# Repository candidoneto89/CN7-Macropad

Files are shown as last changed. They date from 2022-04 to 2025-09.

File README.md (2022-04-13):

# CN7 Macropad

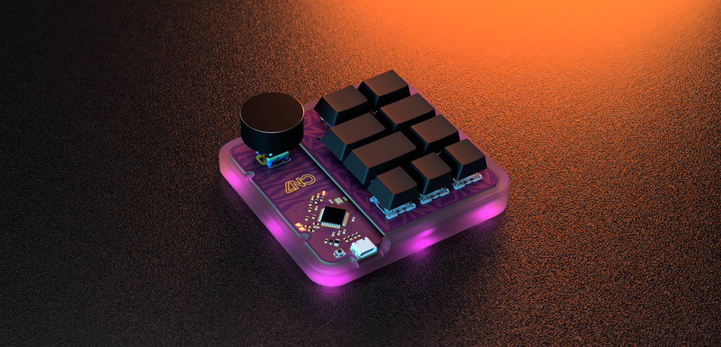
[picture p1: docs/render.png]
CN7 Macropad


**CN7 Macropad** is a custom-built mechanical keyboard, packing features:
- 9 programmable keys made for shortcuts;
- layer-indication LEDs;
- rotary encoder for commands such as media control and CAD features like zoom, etc;
- RGB addressable LEDs for underglow and individual key-lightning;

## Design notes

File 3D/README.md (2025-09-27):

## Building partlist:

Stacked Acrylic:
- 8x M2x6mm screws
- 4x M2x2mm screws
- 4x M2x12mm round standoffs
- 2x M2x6mm round standoffs

Open case:
- 3x M2 threaded inserts
- 3x M2x10mm screw

Closed case:
- 4x M2 threaded inserts
- 4x M2x10mm screw
- 1x 27x44x3mm acrylic sheet
- 1x 84x78x3mm acrylic sheet

## Stacked Acrylic 
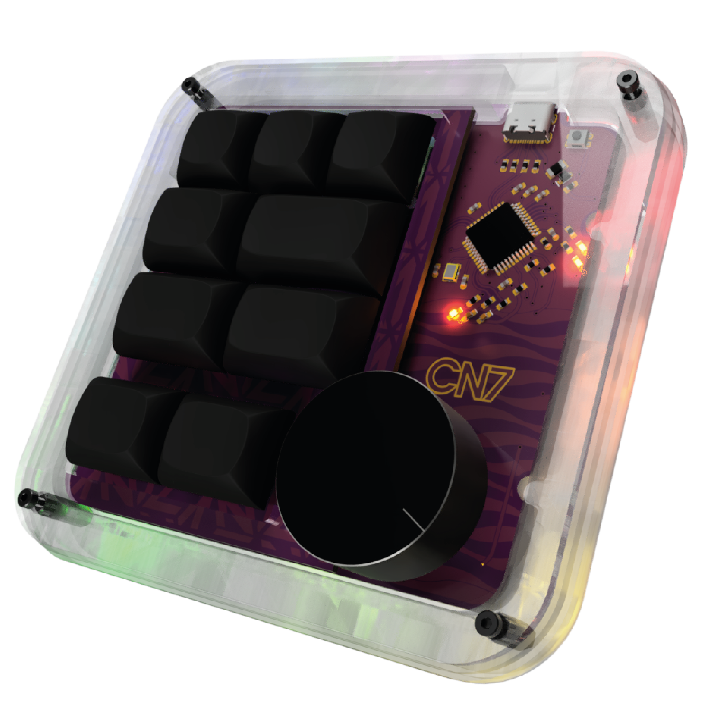
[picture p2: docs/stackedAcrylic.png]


## Open Case 
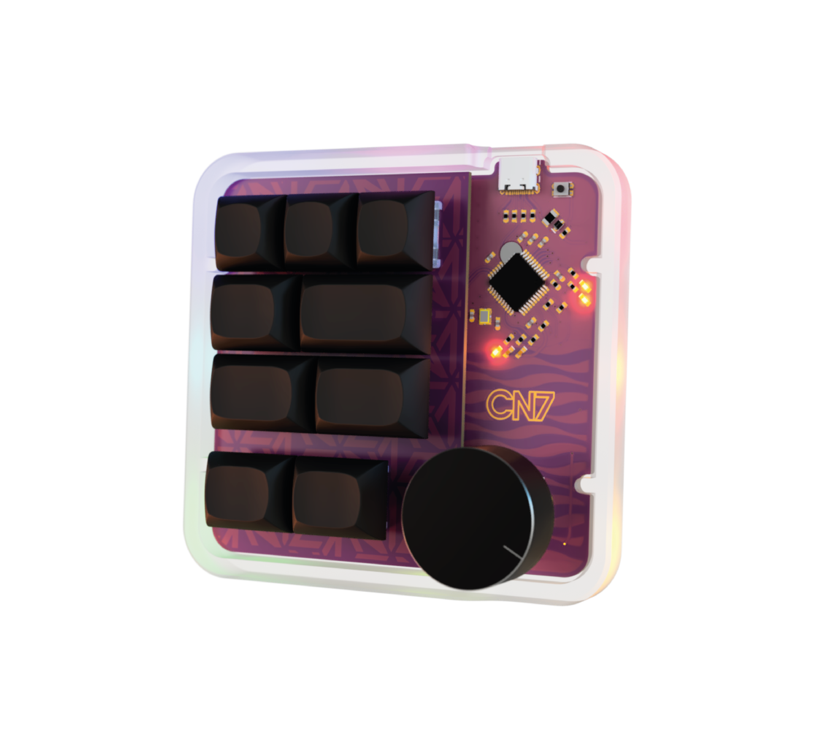
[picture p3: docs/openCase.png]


## Closed Case 
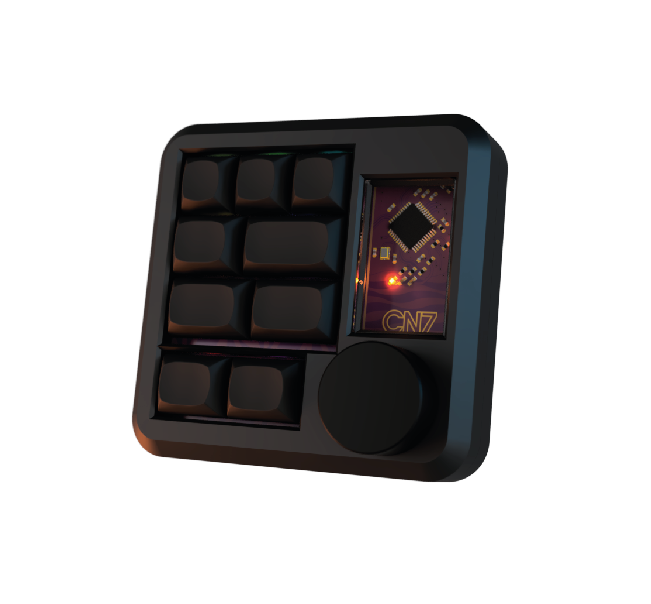
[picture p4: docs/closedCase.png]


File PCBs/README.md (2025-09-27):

# BOM
|Parts |Value |Package |Qty |
|---|---|---|---|
|C1 |10uF |0603-CAP |1 |
|C2, C3, C4, C5, C6 |1.0uF |0603-CAP |5 |
|C7, C8 |22pF |0603-CAP |2 |
|C9, C10, C11, C12, C13, C14, C15, C16, <br>C17, C18, C19, C20, C21, C22, C23, C24, C25|0.1uf|0603|17 |
|D1 |3A/10V/280mV |SOD-323 |1 |
|D12, D13 | |SOD-523 |2 |
|D2, D3, D4, D14, D15 | |LED-0603 |5 |
|D5, D6, D7, D8, D9, D10, D11 | |SOD-523 |7 |
|J2 |USB-C Connector |GCT_USB4105_REVA |1 |
|LED_1, LED_2, LED_3, LED_4, LED_5, LED_6, LED_7, LED_8, LED_9|SK6812-MINI-E|SK6812-MINI-E |9 |
|LED_10 |WS2812B5050 |WS2812B |1 |
|LED_11, LED_12, LED_13, LED_14, LED_15, LED_16, LED_17 |WS2812B5050 |WS2812B |7 |
|R1, R2 |5.1k |R0603 |2 |
|R10, R11, R12, R14, R15 |200 |R0603 |5 |
|R3, R4 |22 |R0603 |2 |
|R5, R6, R7, R8, R13 |10k |R0603 |5 |
|R9 |500 |R0603 |1 |
|S2 |KMR621NGLFS |SW_KMR621NGLFS |1 |
|SW10 |EC11B-V-T |EC11B-V |1 |
|SW1, SW2, SW3, SW4, SW5, SW6, SW7, SW8, SW9 |KAILH |HOT-SWAP SOCKET |9 |
|U$1 |PTC-FUSE |PTC1206 |1 |
|U1 |ATMEGA32U4 |TQFP44 |1 |
|Y2 |CRYSTAL |SMD-3.2X2.5MM |1 |

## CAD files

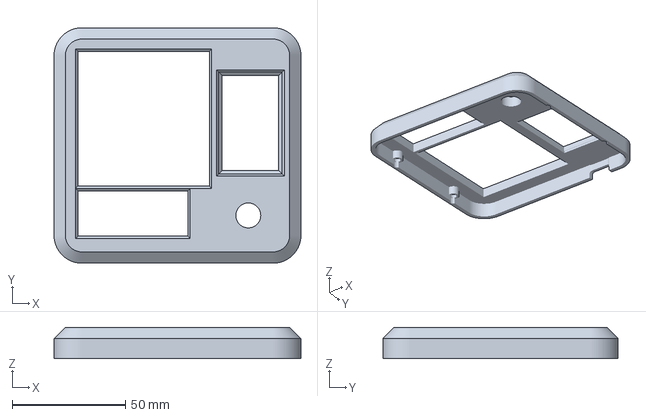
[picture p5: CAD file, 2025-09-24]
3D/[closedCase] Top.3mf
109.0 x 103.9 x 13.9 mm

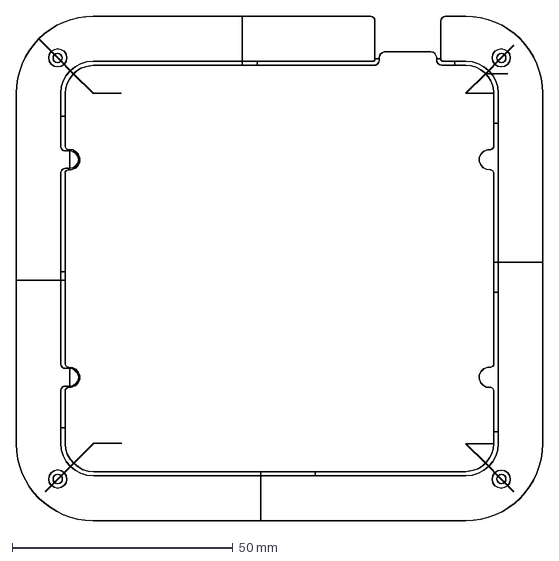
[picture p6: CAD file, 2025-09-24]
3D/acryliccase/4-openspacer2-round.dxf
119.2 x 114.1 mm

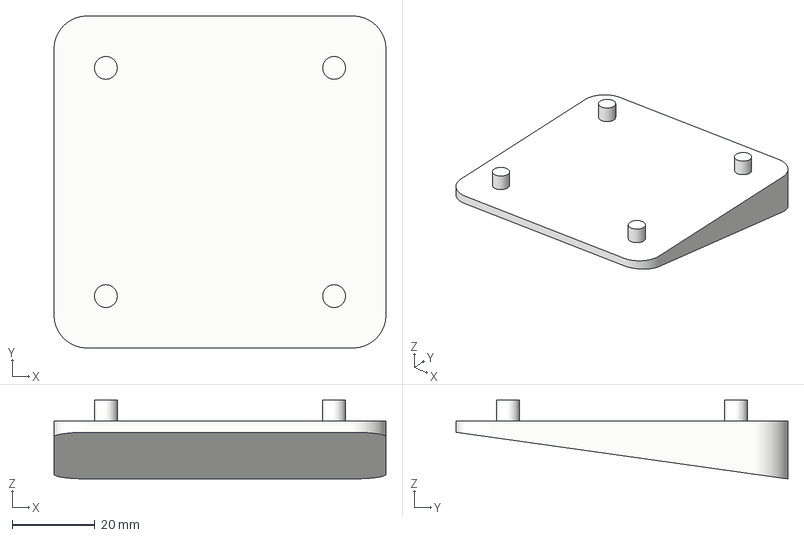
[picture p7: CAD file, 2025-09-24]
3D/[openCase] Feet.3mf
80.0 x 80.0 x 19.0 mm

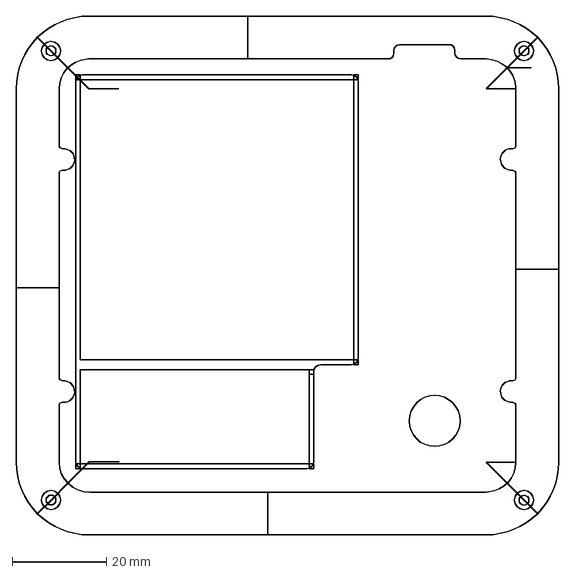
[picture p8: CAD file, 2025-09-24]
3D/acryliccase/6-top.dxf
115.2 x 110.1 mm

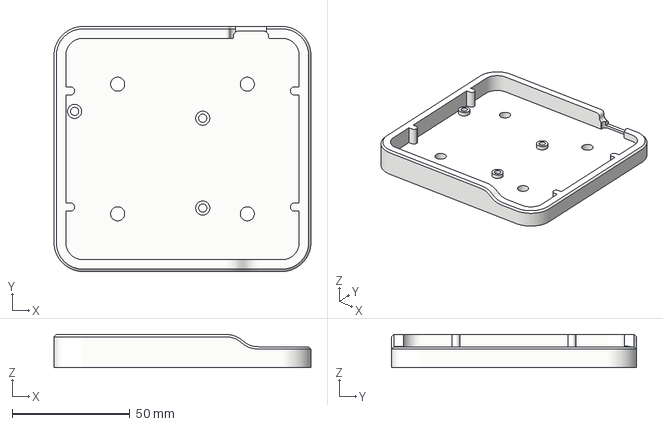
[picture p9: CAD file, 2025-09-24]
3D/[openCase] BaseStand.3mf
109.0 x 103.9 x 14.0 mm

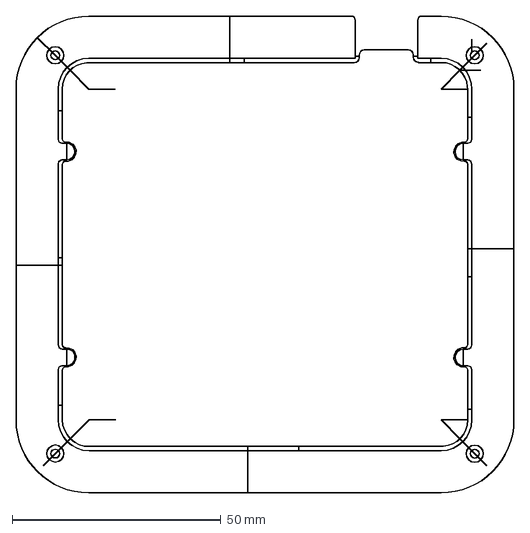
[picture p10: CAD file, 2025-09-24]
3D/acryliccase/3-openspacer1-round.dxf
119.2 x 114.1 mm

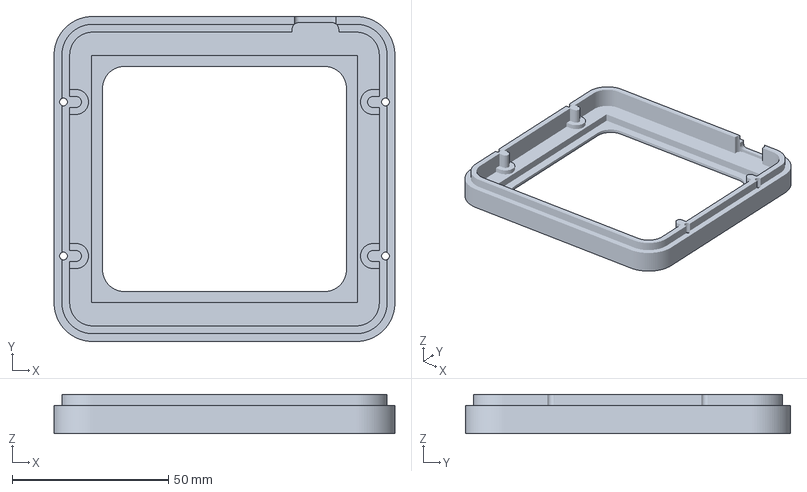
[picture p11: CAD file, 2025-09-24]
3D/[closedCase] Base.3mf
109.0 x 103.9 x 12.5 mm

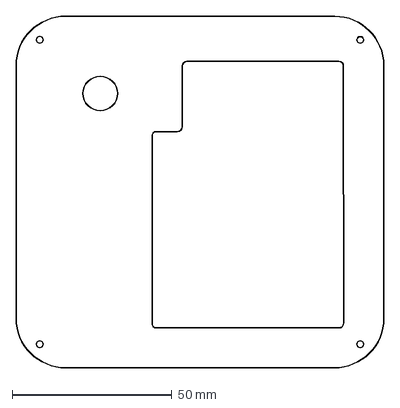
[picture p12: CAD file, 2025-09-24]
3D/acryliccase/teste.dxf
115.2 x 110.1 mm

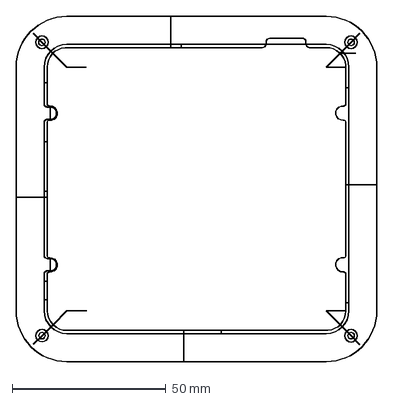
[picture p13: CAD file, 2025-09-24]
3D/acryliccase/5-closedspacer2-round.dxf
117.2 x 112.1 mm

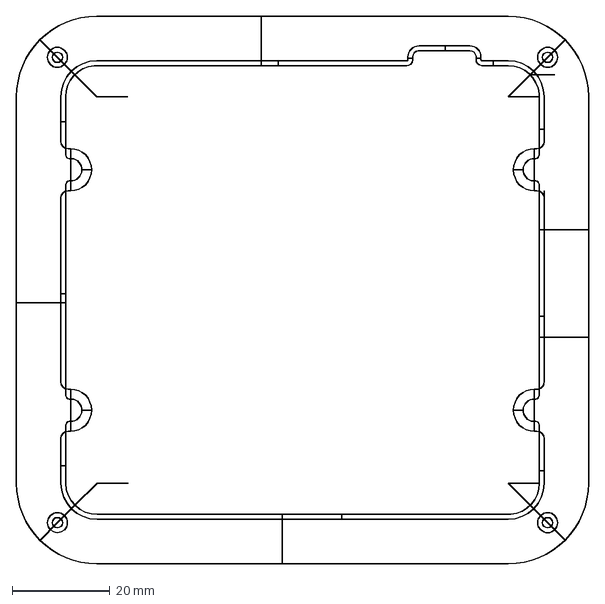
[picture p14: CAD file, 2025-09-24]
3D/acryliccase/2-closedspacer1-round.dxf
117.2 x 112.1 mm

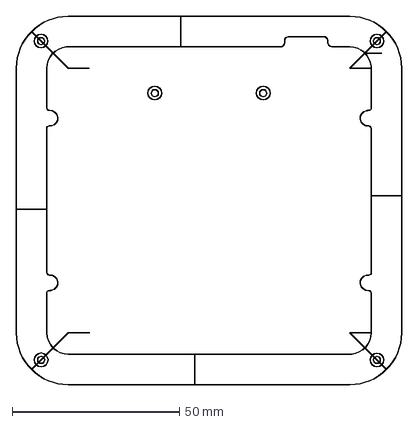
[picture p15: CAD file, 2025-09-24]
3D/acryliccase/1-bottom.dxf
115.2 x 110.1 mm

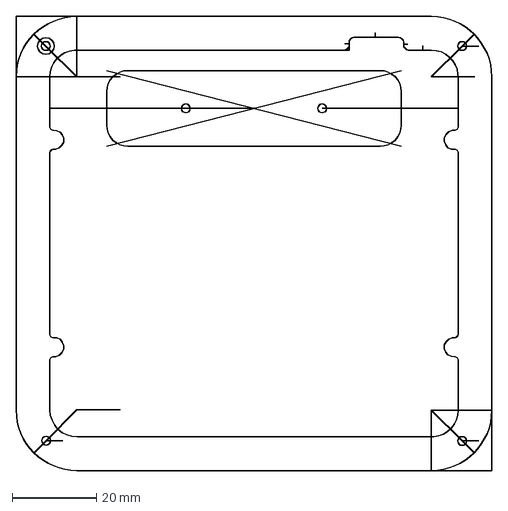
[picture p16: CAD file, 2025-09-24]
3D/acryliccase/9-feet3.dxf
113.0 x 107.9 mm

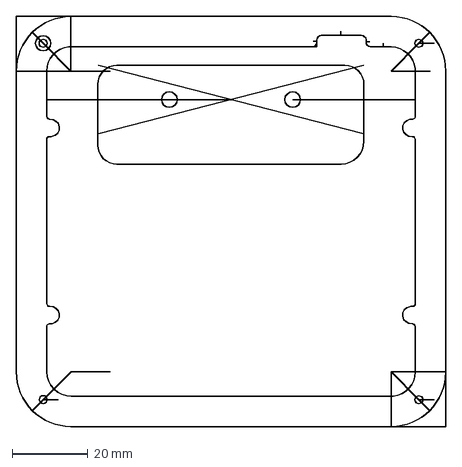
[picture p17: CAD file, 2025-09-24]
3D/acryliccase/8-feet2.dxf
113.0 x 107.9 mm

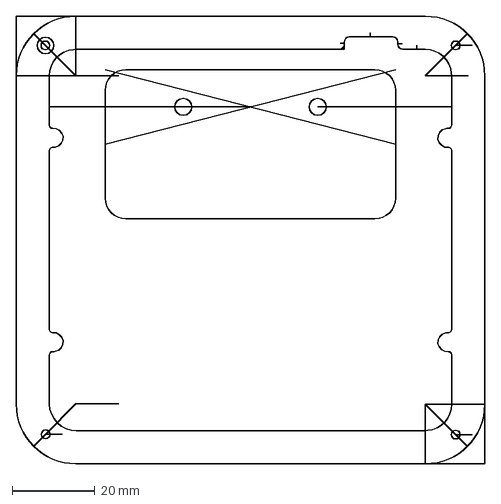
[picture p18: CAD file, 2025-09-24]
3D/acryliccase/7-feet1.dxf
113.0 x 107.9 mm

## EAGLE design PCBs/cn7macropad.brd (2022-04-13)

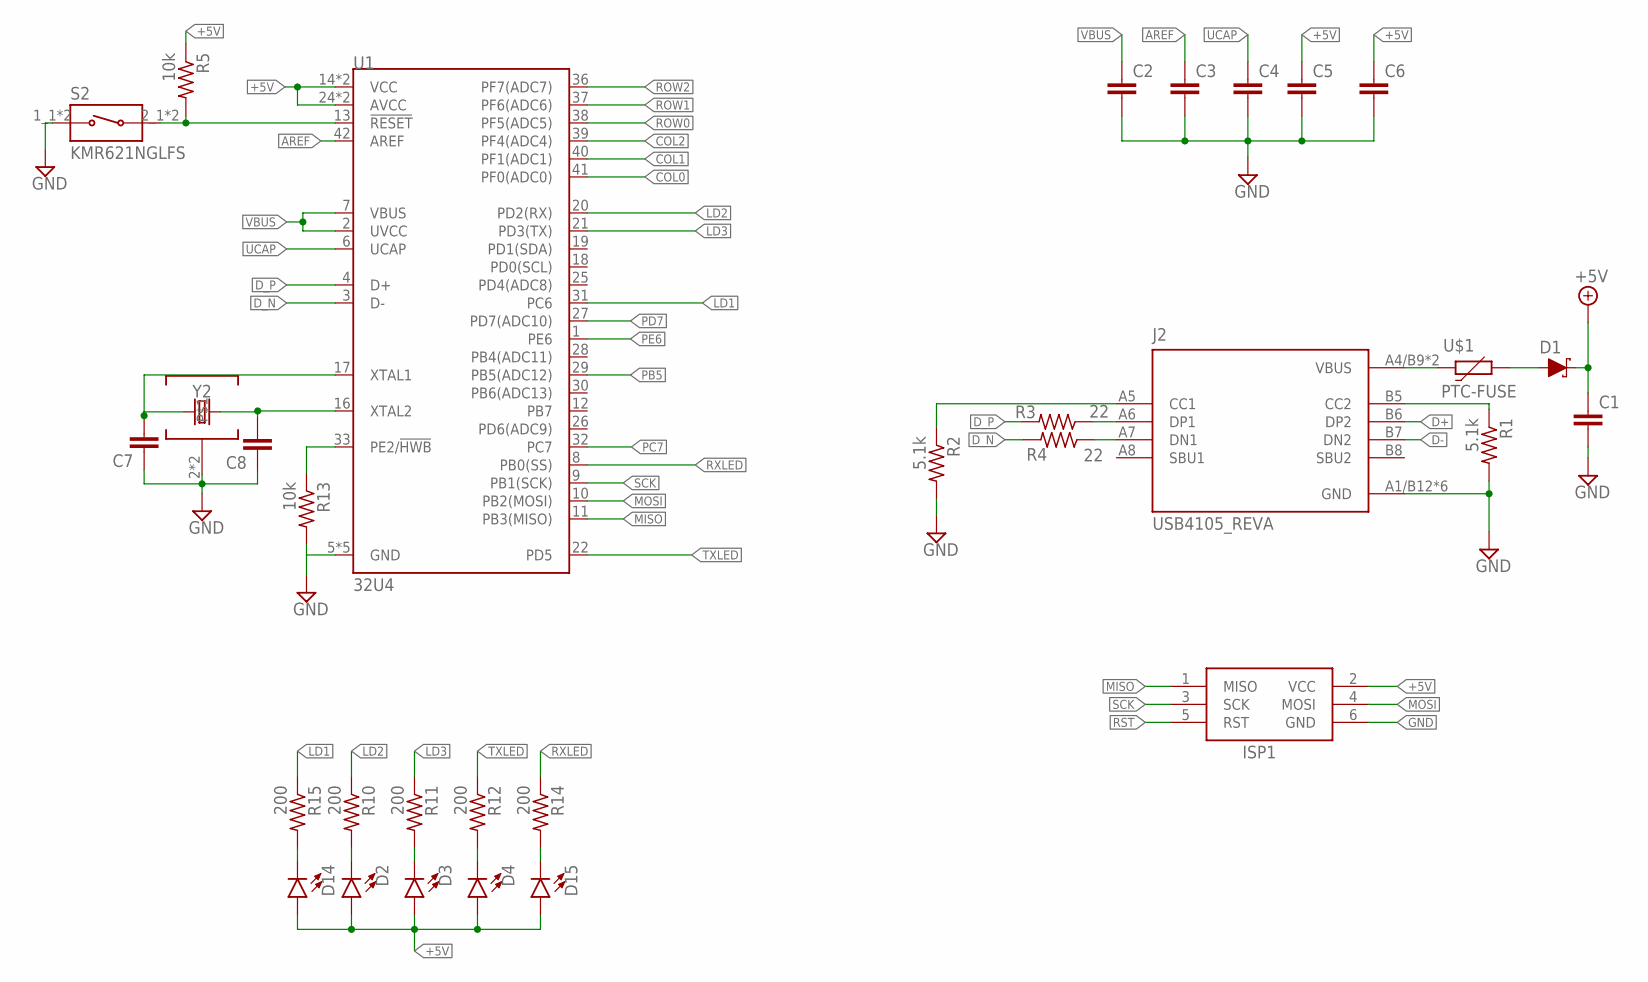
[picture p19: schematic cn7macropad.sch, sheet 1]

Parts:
C1: 10uF; 0603
C2, C3, C4, C5, C6: 1.0uF; 0603
C7, C8: 22pF; 0603
D1: 3A/10V/280mV; SOD-323
D2, D3, D4, D14, D15: LED0603; LED-0603
ISP1: AVRISP-6; AVRISP
J2: USB4105_REVA; GCT_USB4105_REVA
R1, R2: 5.1k; R0603
R3, R4: 22; R0603
R5, R13: 10k; R0603
R10, R11, R12, R14, R15: 200; R0603
S2: KMR621NGLFS; SW_KMR621NGLFS
U1: 32U4; TQFP44
U$1: PTC-FUSE; PTC1206
Y2: CRYSTALSMD-3.2X2.5; CRYSTAL-SMD-3.2X2.5MM

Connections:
+5V: C1.1, C5.1, C6.1, D1.C, D2.A, D3.A, D4.A, D14.A, D15.A, ISP1.2 (VCC), R5.1, U1.14 (VCC), U1.24 (AVCC), U1.34 (VCC), U1.44 (AVCC); also elsewhere on the board
AREF: C3.1, U1.42 (AREF)
CC1: J2.A5 (CC1), R2.1
CC2: J2.B5 (CC2), R1.1
COL0: U1.41 (PF0(ADC0)); also elsewhere on the board
COL1: U1.40 (PF1(ADC1)); also elsewhere on the board
COL2: U1.39 (PF4(ADC4)); also elsewhere on the board
D+: J2.A6 (DP1), J2.B6 (DP2), R3.1
D-: J2.A7 (DN1), J2.B7 (DN2), R4.1
D_N: R4.2, U1.3 (D-)
D_P: R3.2, U1.4 (D+)
GND: C1.2, C2.2, C3.2, C4.2, C5.2, C6.2, C7.1, C8.1, ISP1.6 (GND), J2.A1/B12 (GND), J2.B1/A12 (GND), J2.G1 (GND), J2.G2 (GND), J2.G3 (GND), J2.G4 (GND), R1.2, R2.2, R13.2, S2.1_1 (1), S2.1_2 (1), U1.5 (GND), U1.15 (GND), U1.23 (GND), U1.35 (GND), U1.43 (GND), Y2.2, Y2.4; also elsewhere on the board
LD1: R15.1, U1.31 (PC6)
LD2: R10.1, U1.20 (PD2(RX))
LD3: R11.1, U1.21 (PD3(TX))
MISO: ISP1.1 (MISO), U1.11 (PB3(MISO)); also elsewhere on the board
MOSI: ISP1.4 (MOSI), U1.10 (PB2(MOSI))
unnamed: R13.1, U1.33 (PE2/!HWB)
unnamed: D15.C, R14.2
unnamed: D14.C, R15.2
unnamed: D1.A, U$1.2
unnamed: C7.2, U1.17 (XTAL1), Y2.1
unnamed: C8.2, U1.16 (XTAL2), Y2.3 (2)
unnamed: D2.C, R10.2
unnamed: D3.C, R11.2
unnamed: D4.C, R12.2
PB5: U1.29 (PB5(ADC12)); also elsewhere on the board
PC7: U1.32 (PC7); also elsewhere on the board
PD7: U1.27 (PD7(ADC10)); also elsewhere on the board
PE6: U1.1 (PE6)
ROW0: U1.38 (PF5(ADC5)); also elsewhere on the board
ROW1: U1.37 (PF6(ADC6)); also elsewhere on the board
ROW2: U1.36 (PF7(ADC7)); also elsewhere on the board
RST: ISP1.5 (RST), R5.2, S2.2_1 (2), S2.2_2 (2), U1.13 (!RESET)
RXLED: R14.1, U1.8 (PB0(SS))
SCK: ISP1.3 (SCK), U1.9 (PB1(SCK))
TXLED: R12.1, U1.22 (PD5)
UCAP: C4.1, U1.6 (UCAP)
VBUS: C2.1, J2.A4/B9 (VBUS), J2.B4/A9 (VBUS), U1.2 (UVCC), U1.7 (VBUS), U$1.1

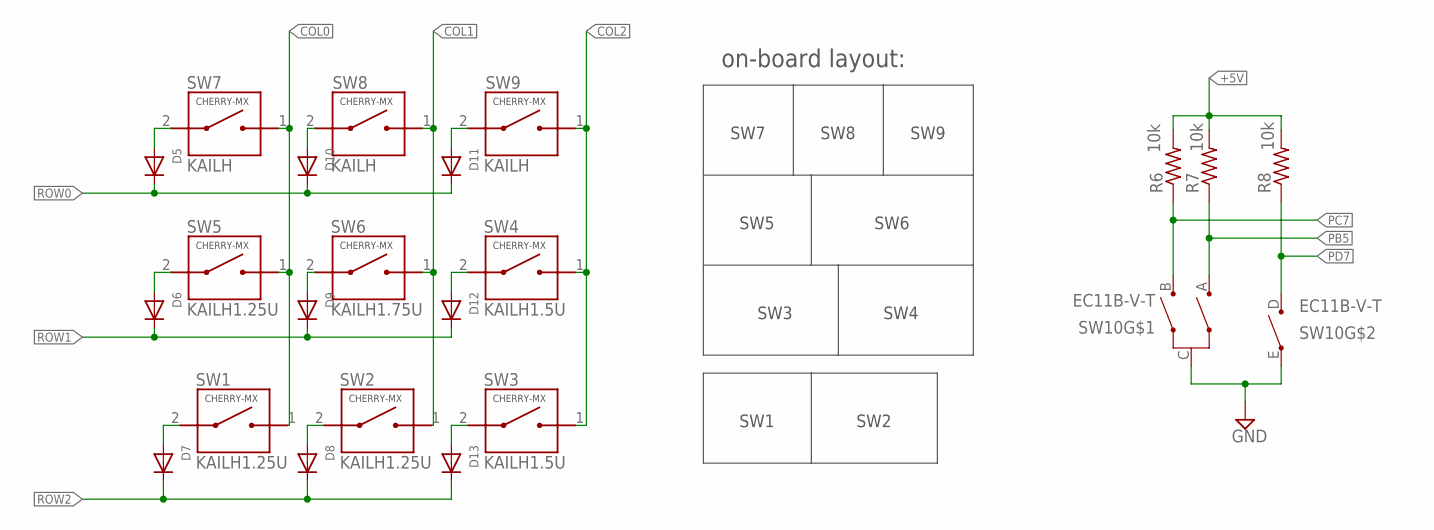
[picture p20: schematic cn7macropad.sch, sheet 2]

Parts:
D5, D6, D7, D8, D9, D10, D11: DIODE; SOD-523
D12, D13: DIODESOD-523; SOD-523
R6, R7, R8: 10k; R0603
SW1, SW2, SW5: KAILH1.25U; SWITCH_SOCKET-1.25U
SW3, SW4: KAILH1.5U; SWITCH_SOCKET-1.5U
SW6: KAILH1.75U; SWITCH_SOCKET-1.75U
SW7, SW8, SW9: KAILH; SWITCH_SOCKET-1U
SW10: EC11B-V-T; EC11B-V

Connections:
+5V: R6.2, R7.2, R8.2; also elsewhere on the board
COL0: SW1.1 (2), SW5.1 (2), SW7.1 (2); also elsewhere on the board
COL1: SW2.1 (2), SW6.1 (2), SW8.1 (2); also elsewhere on the board
COL2: SW3.1 (2), SW4.1 (2), SW9.1 (2); also elsewhere on the board
GND: SW10.C, SW10.E; also elsewhere on the board
unnamed: D5.A, SW7.2 (1)
unnamed: D6.A, SW5.2 (1)
unnamed: D9.A, SW6.2 (1)
unnamed: D10.A, SW8.2 (1)
unnamed: D7.A, SW1.2 (1)
unnamed: D8.A, SW2.2 (1)
unnamed: D13.A, SW3.2 (1)
unnamed: D12.A, SW4.2 (1)
unnamed: D11.A, SW9.2 (1)
PB5: R7.1, SW10.A; also elsewhere on the board
PC7: R6.1, SW10.B; also elsewhere on the board
PD7: R8.1, SW10.D; also elsewhere on the board
ROW0: D5.K (C), D10.K (C), D11.K (C); also elsewhere on the board
ROW1: D6.K (C), D9.K (C), D12.K (C); also elsewhere on the board
ROW2: D7.K (C), D8.K (C), D13.K (C); also elsewhere on the board

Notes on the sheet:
on-board layout:
SW1
SW2
SW3
SW4
SW6
SW5
SW7
SW8
SW9

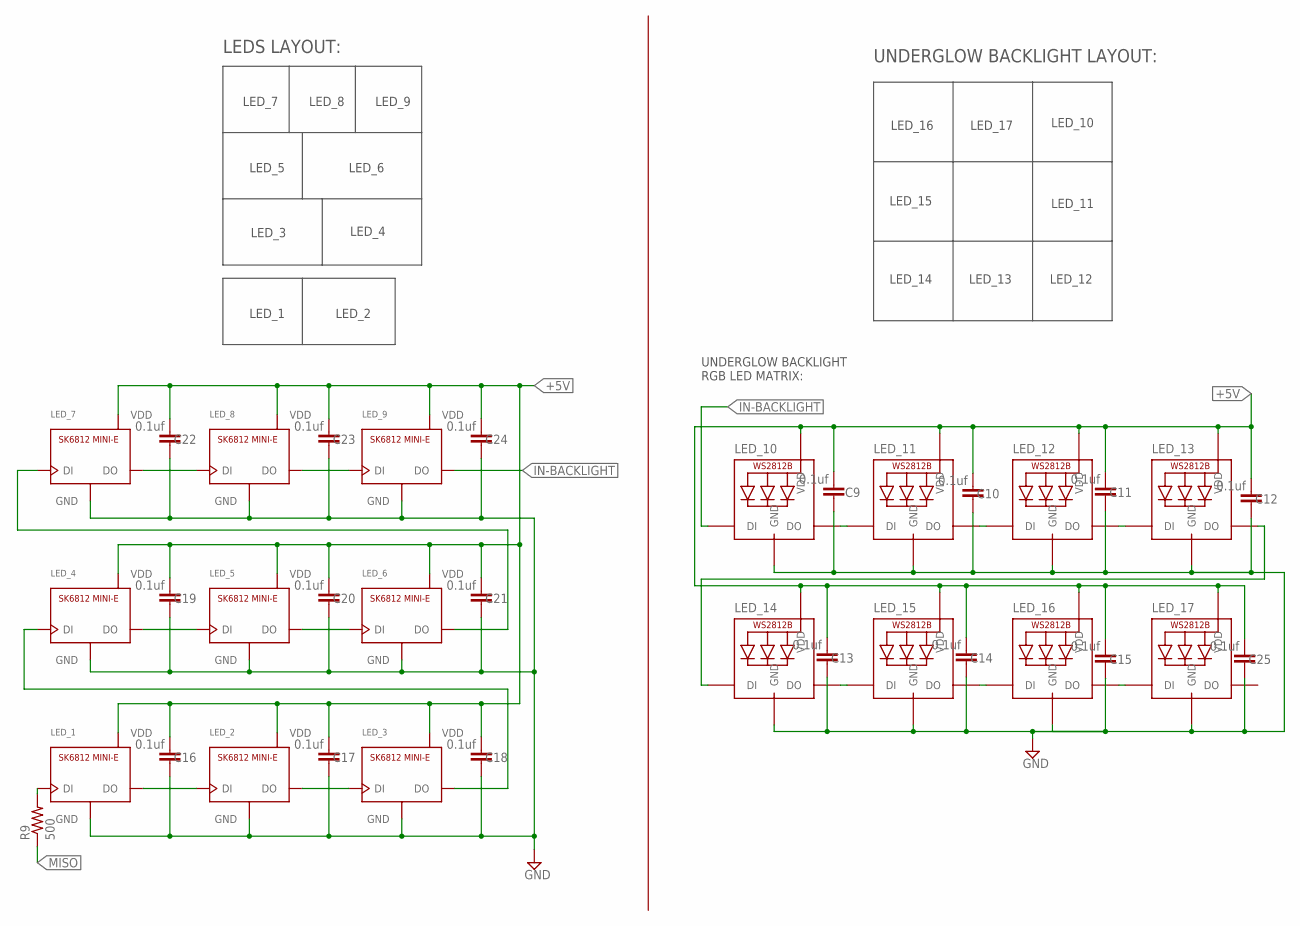
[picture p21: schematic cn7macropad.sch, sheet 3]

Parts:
C9, C10, C11, C12, C13, C14, C15, C16, C17, C18, C19, C20, C21, C22, C23, C24, C25: 0.1uf; 0603
LED_1, LED_2, LED_3, LED_4, LED_5, LED_6, LED_7, LED_8, LED_9: SK6812-MINI-ESW; SK6812-MINI-E
LED_10, LED_11, LED_12, LED_13, LED_14, LED_15, LED_16, LED_17: WS2812B5050; WS2812B
R9: 500; R0603

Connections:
+5V: C9.2, C10.2, C11.2, C12.2, C13.2, C14.2, C15.2, C16.2, C17.2, C18.2, C19.2, C20.2, C21.2, C22.2, C23.2, C24.2, C25.2, LED_1.1-VDD (VDD), LED_2.1-VDD (VDD), LED_3.1-VDD (VDD), LED_4.1-VDD (VDD), LED_5.1-VDD (VDD), LED_6.1-VDD (VDD), LED_7.1-VDD (VDD), LED_8.1-VDD (VDD), LED_9.1-VDD (VDD), LED_10.1-VDD (VDD), LED_11.1-VDD (VDD), LED_12.1-VDD (VDD), LED_13.1-VDD (VDD), LED_14.1-VDD (VDD), LED_15.1-VDD (VDD), LED_16.1-VDD (VDD), LED_17.1-VDD (VDD); also elsewhere on the board
GND: C9.1, C10.1, C11.1, C12.1, C13.1, C14.1, C15.1, C16.1, C17.1, C18.1, C19.1, C20.1, C21.1, C22.1, C23.1, C24.1, C25.1, LED_1.3-GND (GND), LED_2.3-GND (GND), LED_3.3-GND (GND), LED_4.3-GND (GND), LED_5.3-GND (GND), LED_6.3-GND (GND), LED_7.3-GND (GND), LED_8.3-GND (GND), LED_9.3-GND (GND), LED_10.3-GND (GND), LED_11.3-GND (GND), LED_12.3-GND (GND), LED_13.3-GND (GND), LED_14.3-GND (GND), LED_15.3-GND (GND), LED_16.3-GND (GND), LED_17.3-GND (GND); also elsewhere on the board
IN-BACKLIGHT: LED_9.2-DOUT (DO), LED_10.4-DIN (DI)
MISO: R9.1; also elsewhere on the board
unnamed: LED_1.2-DOUT (DO), LED_2.4-DIN (DI)
unnamed: LED_2.2-DOUT (DO), LED_3.4-DIN (DI)
unnamed: LED_1.4-DIN (DI), R9.2
unnamed: LED_3.2-DOUT (DO), LED_4.4-DIN (DI)
unnamed: LED_4.2-DOUT (DO), LED_5.4-DIN (DI)
unnamed: LED_5.2-DOUT (DO), LED_6.4-DIN (DI)
unnamed: LED_6.2-DOUT (DO), LED_7.4-DIN (DI)
unnamed: LED_7.2-DOUT (DO), LED_8.4-DIN (DI)
unnamed: LED_8.2-DOUT (DO), LED_9.4-DIN (DI)
unnamed: LED_10.2-DOUT (DO), LED_11.4-DIN (DI)
unnamed: LED_11.2-DOUT (DO), LED_12.4-DIN (DI)
unnamed: LED_13.2-DOUT (DO), LED_14.4-DIN (DI)
unnamed: LED_14.2-DOUT (DO), LED_15.4-DIN (DI)
unnamed: LED_15.2-DOUT (DO), LED_16.4-DIN (DI)
unnamed: LED_16.2-DOUT (DO), LED_17.4-DIN (DI)
unnamed: LED_12.2-DOUT (DO), LED_13.4-DIN (DI)

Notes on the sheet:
LEDS LAYOUT:
LED_1
LED_2
LED_3
LED_4
LED_6
LED_5
LED_7
LED_8
LED_9
UNDERGLOW BACKLIGHT LAYOUT:
LED_10
LED_11
LED_12
LED_13
LED_14
LED_15
LED_16
UNDERGLOW BACKLIGHT RGB LED MATRIX:
LED_17

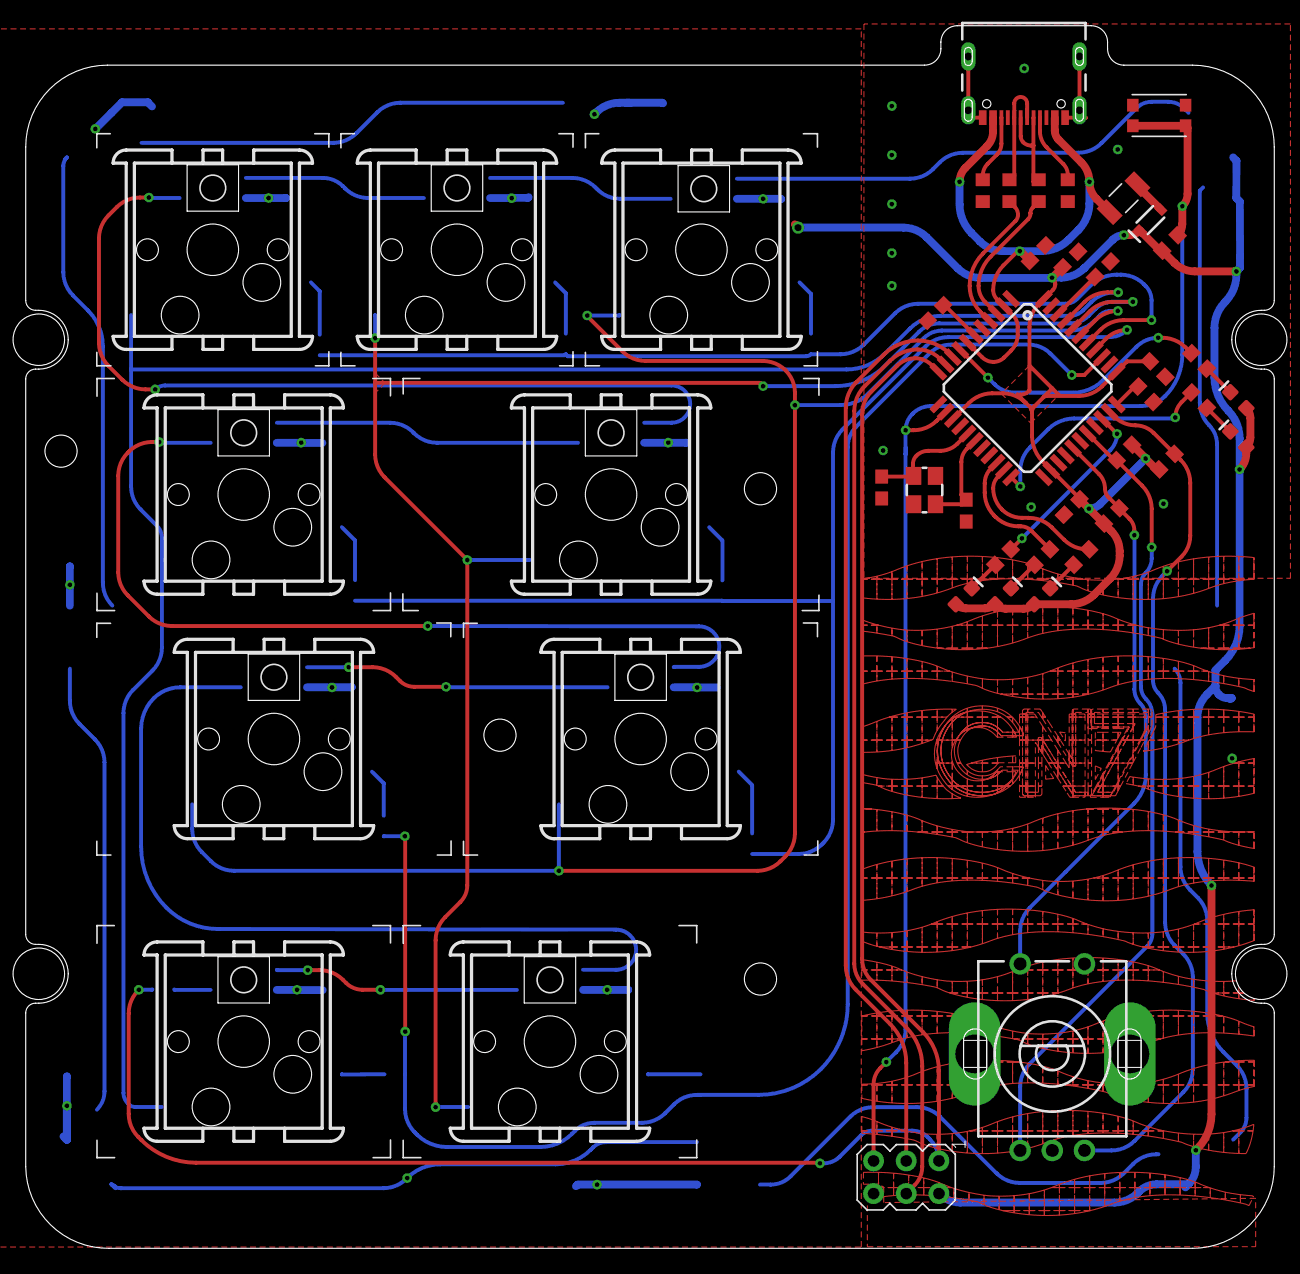
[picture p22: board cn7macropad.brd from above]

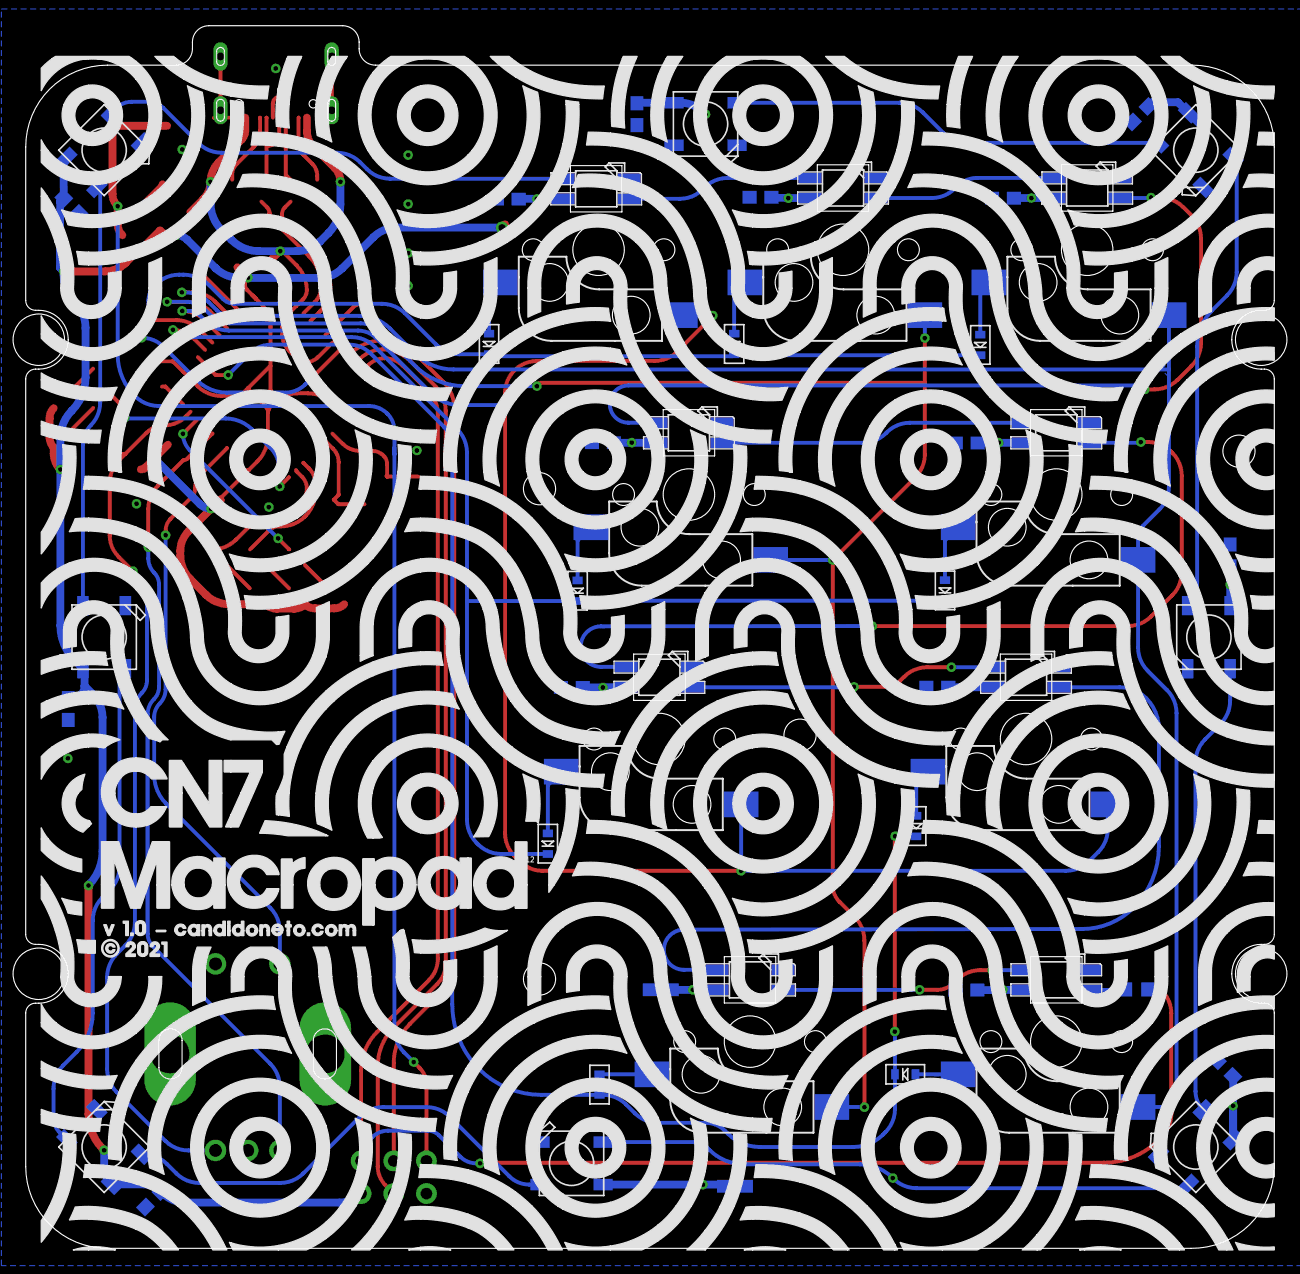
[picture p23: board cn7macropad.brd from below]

Board: 2 copper layers, 97.0 x 95.0 mm, 88 parts (35 on the bottom side), 64 nets.

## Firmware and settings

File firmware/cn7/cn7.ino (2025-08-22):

/*
Keys Layout:

 K7 K8 K9
 K5 K6
 K3 K4
 -  -
 K1 K2

 Matrix Layout:

 K7 K8 K9 - A2
 K5 K6 K4 - A1
 K1 K2 K3 - A0
 |  |  |
 A5 A4 A3 (Leonardo pins)
 
*/

#include <Adafruit_NeoPixel.h> 
#include <RotaryEncoder.h>
#include "HID-Project.h"
#include "led_animations.h"

#define PIN 14 //MISO PIN
#define NUM 18

Adafruit_NeoPixel pixels = Adafruit_NeoPixel(NUM, PIN, NEO_GRB + NEO_KHZ800);

int macropadPins[6] = {A2, A1, A0, A5, A4, A3};
int macropadRows[3] = {A2, A1, A0};
int macropadColumns[3] = {A5, A4, A3};

// Encoder pins:
int encoderA = 9;
int encoderB = 13;
int encoderC = 6;
volatile long lastPos = 0;

RotaryEncoder encoder(encoderA, encoderB);

// Layer indicator LED pins:
int led1 = 5; // PC6 (pin 5 on Leonardo)
int led2 = 0; // PD2 (pin 0 on Leonardo)
int led3 = 1; // PD3 (pin 1 on Leonardo)
const int leds[] = {led1, led2, led3};

int layerMode = 1;

int macropadRead;  // Used to monitor which buttons are pressed.
int timeout;  // timeout variable used in loop
char keys[3][3] = {
  {'7','8','9'},
  {'5','6','4'},
  {'1','2','3'},
};

void sendKeyPress1(char key);
void sendKeyPress2(char key);
void sendKeyPress3(char key);
void (*sendKeyFuncs[])(char) = { nullptr, sendKeyPress1, sendKeyPress2, sendKeyPress3 };

void setup()
{
  Serial.begin(9600);
  Consumer.begin();
  Keyboard.begin();
  pixels.begin();
 
  for (int i=0; i<6; i++)
  {
    pinMode(macropadPins[i], INPUT);      // Set all keypad pins as inputs
    digitalWrite(macropadPins[i], HIGH);  // Pull all keypad pins high
  }

  // Setting the layer indicator LEDs pins as output
  DDRC = DDRC | B01000000;  
  PORTC = B00000000;
  DDRD = DDRD | B00001100;  
  PORTD = B00000000;
  
  // Setting up Timer Interrupt:
  cli();
  TCCR1A = 0;
  TCCR1B = 0;

  TCCR1B |= B00000100;
  TIMSK1 |= B00000010;
  OCR1A = 1000;
  sei();
}

void loop()
{
  rgbLoop();
}

ISR(TIMER1_COMPA_vect){
  TCNT1  = 0; 

  encoder.tick();

  if(readEncButton()) {
    if (layerMode == 3) layerMode=1;
    else layerMode++;
  }

  switch(layerMode) {
    case 1:
      setLed(1);
      encoder1();
      break;    
    case 2:
      setLed(2);
      encoder2();
      break;
    case 3:
      setLed(3);
      encoder3();
      break;
  }
 
  macropadRead = readKeypad();  // read which buttons are pressed
  if (macropadRead)             // if a button is pressed 
  {
    sendKeyFuncs[layerMode](macropadRead);
    // sendKeyPress(macropadRead);  // send the button over USB
    timeout = 2000;              // top of the repeat delay
    while ((readKeypad() == macropadRead) && (--timeout))  // Decrement timeout and check if key is being held down
      delayMicroseconds(1);
    while (readKeypad() == macropadRead)  // while the same button is held down
    {
      sendKeyFuncs[layerMode](macropadRead);
      // sendKeyPress(macropadRead);  // continue to send the button over USB
      delay(50);  // 50ms repeat rate
    }
  }
}

void setLed(int index) {
  for (int i = 0; i < 3; i++) {
    digitalWrite(leds[i], i == (index-1) ? LOW : HIGH);
  }
}


boolean readEncButton(void)
{
  if(!digitalRead(encoderC)){
    delay(50);
    if(!digitalRead(encoderC)) {
      while(!digitalRead(encoderC));
      return true;
    }
  }
  return false;
}

void sendKeyPress1(char key)
{
  switch(key)
  {
    case '1':  // 0x001
      Keyboard.press(KEY_LEFT_CTRL);
      Keyboard.write('c');
      Keyboard.releaseAll();  
      break;
    case '2':  // 0x002
      Keyboard.press(KEY_LEFT_CTRL);
      Keyboard.write('v');
      Keyboard.releaseAll();  
      break;
    case '3':  // 0x004
      //Keyboard.write('3');
      break;
    case '4':  // 0x008
      //Keyboard.write('4');
      break;
    case '5':  // 0x010
      //Keyboard.write('5');
      break;
    case '6':  // 0x020
      //Keyboard.write('6');
      break;
    case '7':  // 0x040
      //Keyboard.write('7');
      break;
    case '8':  // 0x080
      Keyboard.write('8');
      break;
    case '9':  // 0x100
      Keyboard.write('9');
      break;
  }
}

void sendKeyPress2(char key)
{
  switch(key)
  {
    case '1':  // 0x001
      Keyboard.press(KEY_LEFT_CTRL);
      Keyboard.write('+');
      Keyboard.releaseAll();  
      break;
    case '2':  // 0x002
      Keyboard.press(KEY_LEFT_CTRL);
      Keyboard.write('-');
      Keyboard.releaseAll();  
      break;
    case '3':  // 0x004
      Keyboard.press(KEY_LEFT_CTRL);
      Keyboard.write('0');
      Keyboard.releaseAll();  
      break;
    case '4':  // 0x008
      //Keyboard.write('4');
      break;
    case '5':  // 0x010
      //Keyboard.write('5');
      break;
    case '6':  // 0x020
      //Keyboard.write('6');
      break;
    case '7':  // 0x040
      //Keyboard.write('7');
      break;
    case '8':  // 0x080
      //Keyboard.write('8');
      break;
    case '9':  // 0x100
      //Keyboard.write('9');
      break;
  }
}

void sendKeyPress3(char key)
{
  switch(key)
  {
    case '1':  // 0x001
      Keyboard.press(KEY_LEFT_CTRL);
      Keyboard.write('c');
      Keyboard.releaseAll();  
      break;
    case '2':  // 0x002
      Keyboard.press(KEY_LEFT_CTRL);
      Keyboard.write('v');
      Keyboard.releaseAll();  
      break;
    case '3':  // 0x004
      //Keyboard.write('3');
      break;
    case '4':  // 0x008
      //Keyboard.write('4');
      break;
    case '5':  // 0x010
      //Keyboard.write('5');
      break;
    case '6':  // 0x020
      //Keyboard.write('6');
      break;
    case '7':  // 0x040
      //Keyboard.write('7');
      break;
    case '8':  // 0x080
      //Keyboard.write('8');
      break;
    case '9':  // 0x100
      //Keyboard.write('9');
      break;
  }
}

void encoder1() {
  long newPos = encoder.getPosition();
  if (newPos != lastPos) {
    if (newPos > lastPos) {
      Consumer.write(MEDIA_VOL_UP);
    } else {
      Consumer.write(MEDIA_VOL_DOWN);
    }
    lastPos = newPos;
  }
}

void encoder2() {
  long newPos = encoder.getPosition();
  if (newPos != lastPos) {
    if (newPos > lastPos) {
      Keyboard.press(KEY_LEFT_CTRL);
      Keyboard.write('-');
      Keyboard.releaseAll(); 
    } else {
      Keyboard.press(KEY_LEFT_CTRL);
      Keyboard.write('+');
      Keyboard.releaseAll(); 
    }
    lastPos = newPos;
  }
}

void encoder3() {
  long newPos = encoder.getPosition();
  if (newPos != lastPos) {
    if (newPos > lastPos) {
      Consumer.write(MEDIA_VOL_UP);
    } else {
      Consumer.write(MEDIA_VOL_DOWN);
    }
    lastPos = newPos;
  }
}

char readKeypad()
{
  char result = 0;  
 
  for (int i=0; i<6; i++)
  {
    pinMode(macropadPins[i], INPUT);
    digitalWrite(macropadPins[i], HIGH);
  }
 
  for (int row=0; row<3; row++)
  {
    pinMode(macropadRows[row], OUTPUT);  
    digitalWrite(macropadRows[row], LOW);  
    for (int col=0; col<3; col++)
    {  
      if (!digitalRead(macropadColumns[col])) result = keys[row][col];
    }
    digitalWrite(macropadRows[row], HIGH);
  }
  return result;
}

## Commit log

2022-04-13 adding boards
    [cn7macropad-pure.brd, cn7macropad-pure.sch, cn7macropad-v2.brd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]
2025-08-22 small improvements on code
    [plate-cn7.brd]
2025-09-24 added 3D case files
    [1-bottom.dxf, 2-closedspacer1-round.dxf, 3-openspacer1-round.dxf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]

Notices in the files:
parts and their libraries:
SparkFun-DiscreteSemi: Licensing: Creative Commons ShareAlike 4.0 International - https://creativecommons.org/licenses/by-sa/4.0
